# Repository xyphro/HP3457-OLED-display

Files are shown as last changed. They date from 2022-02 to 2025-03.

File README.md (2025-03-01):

# HP3457-OLED-display
A modern replacement for the low contrast HP3457 Multimeter LCD

HP3457 is a great multimeter of the pre Keysight and pre Agilent era from HP.
If you do some research on it, you get to learn a lot of details of how much nice engineering work has been put into the development of this multimeter. It is certainly one of the things, that was developed by great experienced engineers and is a masterpiece in finding proper solutions for technical challenges to push accuracy but also measurement speed on the right level.

HOWEVER: The display is crap. It is a low contrast display with small characters and extremly hard to read under most conditions. When I got mine, I rarely used it just for that reason.

I researched a bit on possible options and found 2 solutions:
- Mount a backlight behind the LCD. This is a very risky task, but I tried it out: The contrast gets even worse and actually it felt even like a downgrade of the display.
- A great sophisticated replacement LED display done by an EEVBlog user called "Xi": [https://www.eevblog.com/forum/projects/led-display-for-hp-3457a-multimeter-i-did-it-)](https://www.eevblog.com/forum/projects/led-display-for-hp-3457a-multimeter-i-did-it-)). Unfortunately this solution requires some difficult production techniques (milling LED displays to insert dots/comma leds, milling PCBs, ...).

I looked for solutions that were simpler to realize, such as matching TFT IPS panels, big OLED screens but failed to find a matching display.

After long thinking I had an idea... Let's use the cheapest OLED display that have very good availability: 0.87" i2c displays from Aliexpress. They are smaller than the required 10mm digit distance and just fit also mechanically into the display housing, without the need to cut pieces of the housing away.

To explain the idea - here 2 pictures:

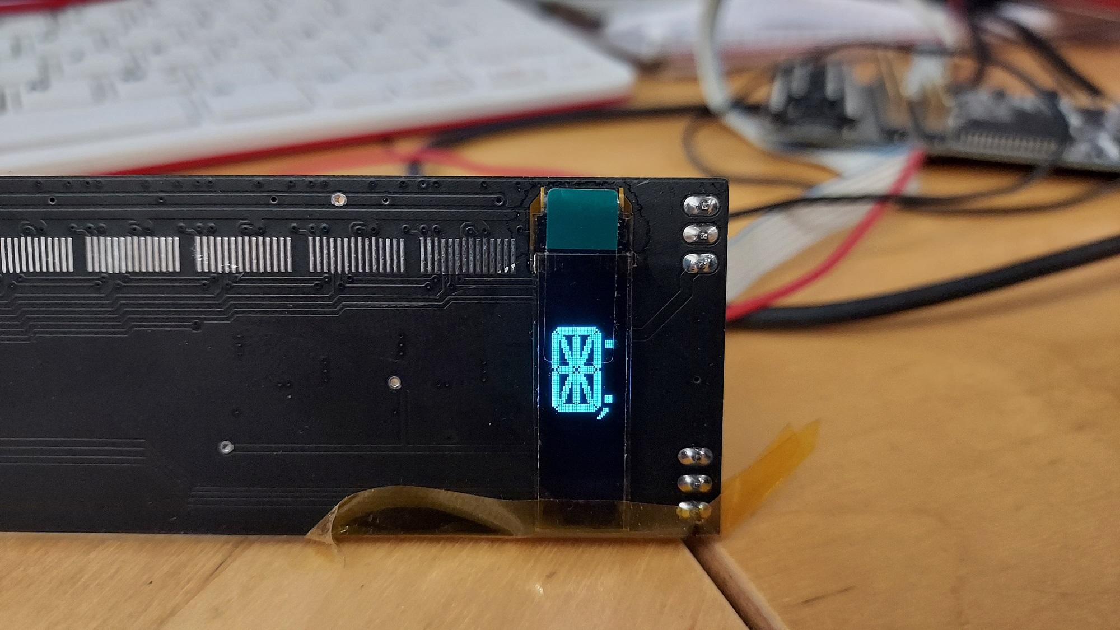
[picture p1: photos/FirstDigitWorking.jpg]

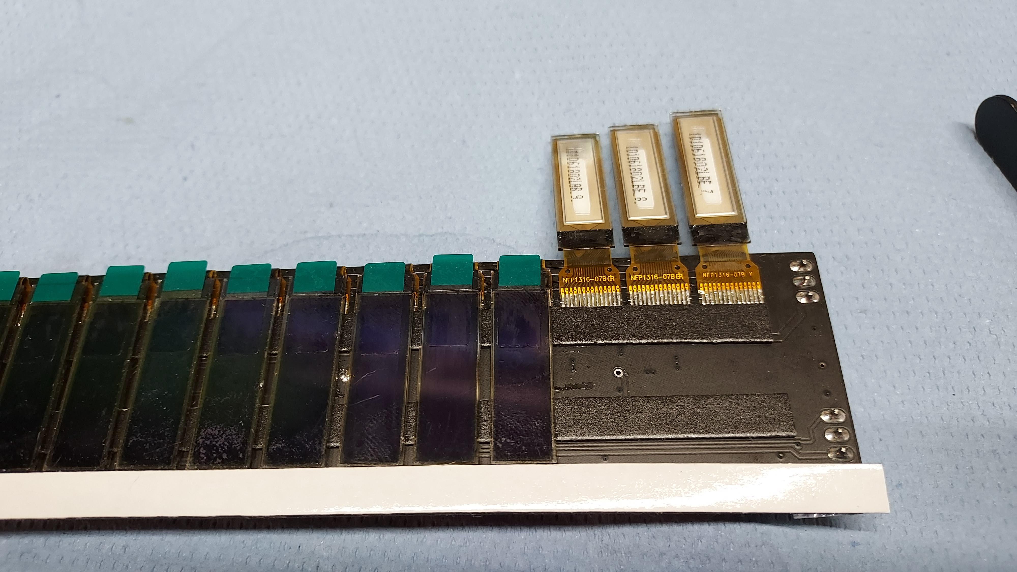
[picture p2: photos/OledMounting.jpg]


# The final result:

This video shows my final solution to the problem:

(https://youtu.be/EYaLf55-z-o) 

(Well, not the most entertaining video in this world, but... It serves the job :-) )

# Building the display yourself:

This repositories contains sourcecode and hw design files in "raw" formats, but also the binary output.

I ordered the PCBs originally at JLCPCB. Both PCBs are located on a single panel and you can cut them in half after receiving them. The Gerber files are located under hardware/gerber.
In case you want to modify the PCB yourself, feel free to do so (but share it back) and use the files located under hardware/eagle to create your own design.

The software was created using Atmel Studio 7.0 and the project can be directly opened with it for editing if desired.

Don't forget to program the fuses of the ATMega8 MCU and select 8 MHz internal RC oscillator as clock source (otherwise it runs too slow with its default 1 MHz clock only).

NOTE: Ensure to buy the 0.87" variant of the OLEDS. There are also popular 0.91" variants available, but they are to wide! 
I bought my displays directly on Aliexpress: https://de.aliexpress.com/item/1005001856921229.html
In case the above link stops working, search for items like "XABL 0.87 Inch OLED"

I personally tested SSD1336 based display. EEVBlog User Miti bought a display with a CH1115 controller. This controller has a different command set. We jointly have added support for CH1115 displays to the code. In case you have such a SSD1336 you will need to rebuild the software with the `#define DISPLAYTYPE_CH1115` being enabled within oled.c. Otherwise the original SSD1336 based OLED displays will be supported.

The prebuilt binaries provided in this repository are built for SSD1336 based displays.

# Annuciators:

Annuciators are the small triangles / TEXT labels underneath the display. They are used to signal state information of the multimeter.

There are 3 different flavors realized. To select them when building the software, edit this define in annuciatorsel.h:
#define ANNUCIATORS_PERSONALITY HP3457_ICONS

And select any of the 3 below ones:

- HP3457_ORIGINAL - These are the small triangles, that rely on the information printed on the frontpanel underneath the display:

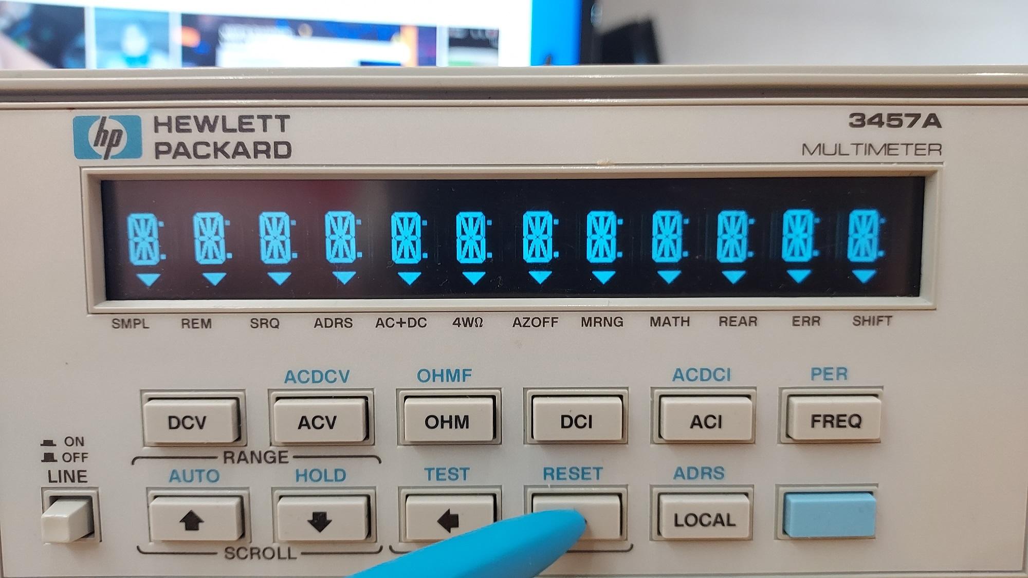
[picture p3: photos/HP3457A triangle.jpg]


- HP3457_ICONS  - Small textual labels on the OLEDS itself:

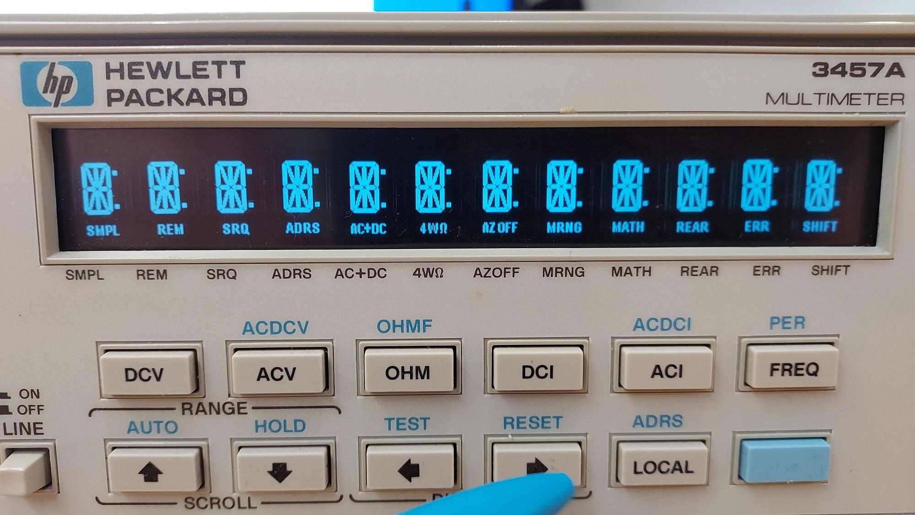
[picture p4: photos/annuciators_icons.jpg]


- HP3478_ICONS - textual labels matching the HP3478 / 3468 display

The software/hex folder also contains precompiled .hex images for those 3 different annuciators versions.

# Putting it together

After soldering the PCBs and flashing the MCU, you can mount the PCB to your lovely HP3457 multimeter. The original press fit DIP socket can be directly plugged into the PCB.
The OLED display requires a second voltage source to power the OLEDs themselfes. This can be an AC supply, but I recommend for the HP3457 to use the 5V voltage regulator in TO220 housing and connect the AC lines to pin 1 and 2, which is 12 V.

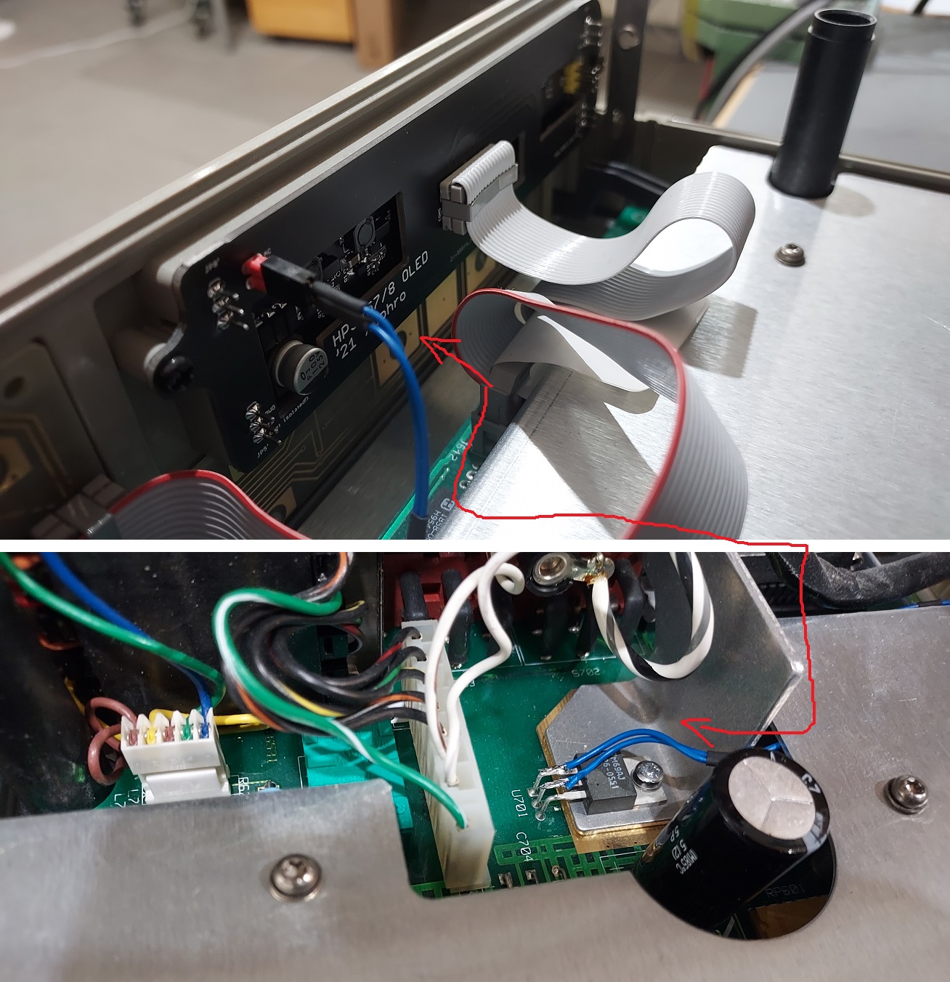
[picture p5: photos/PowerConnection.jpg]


The overall current consumption @12V supply is low and only about 30mA.

After mounting it looks like this from the internal side (the red supply header is unconnected here):

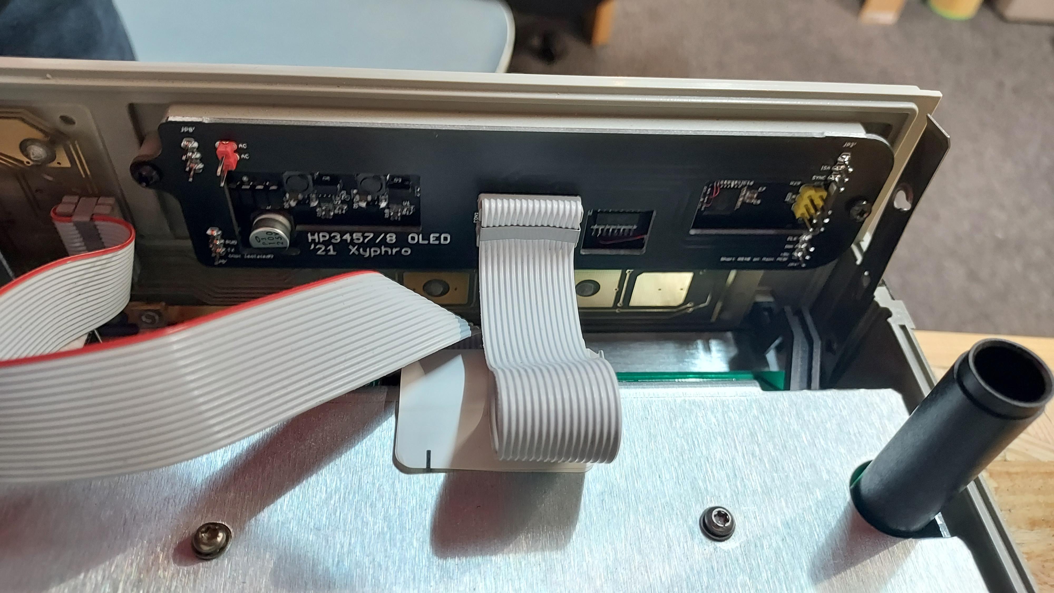
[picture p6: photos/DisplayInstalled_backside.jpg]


Enjoy your shiny new Display :-)

# Update 14th February 2025

## Experience after 3+ years

After 3 years of continuous use the Display still works very well. I have the feeling that the OLEDs got a tiny bit dimmer, but it is still tremendously better as the original LC-Display.

## Command coverage

Before this update (14th February 2025) only commands sent by HP3457a were supported. Though new commands were discovered, which triggered more searching for commands. 
I could find a few more and implemented it. See below table for an overview.

| Command code (12 bit HEX) | Command mnemonic | Implementation status / comment|
|---|---|---|
|028 |	WRA12L | Tested myself on HP3457a. |
|068 |	WRB12L | Tested myself on HP3457a. |
|0a8 |	WRC12L | Tested myself on HP3457a. |
|0e8 |	WRAB6L | Tested with playback of eevblog user Kawal's logic analyzer recording.|
|128 |	WRABC4L  | Not tested with HP instrument, have sent the command manually.|
|168 |	WRAB6R | Not tested with HP instrument, have sent the command manually.|
|1a8 |	WRABC4R  | Not tested with HP instrument, have sent the command manually.|
|1e8 |	WRA1L | Not tested with HP instrument, have sent the command manually.|
|228 |	WRB1L | Not tested with HP instrument, have sent the command manually.|
|268 |	WRC1L | Not tested with HP instrument, have sent the command manually.|
|2a8 |	WRA1R | Not tested with HP instrument, have sent the command manually.|
|2e8 |	WRB1R | Not tested with HP instrument, have sent the command manually.|
|328 |	WRC1R | Not tested with HP instrument, have sent the command manually.|
|368 |	WRAB1R | Not tested with HP instrument, have sent the command manually.|
|3a8 |	WRABC1L  | Not tested with HP instrument, have sent the command manually.|
|3e8 |	WRABC1R  | Not tested with HP instrument, have sent the command manually.|
|230 |  DISOFF | Implemented, but disabled. It results in wrong behavior on HP3457a. This command is supposed to turn the display OFF. It never gets sent on HP3457A.|
|320 |  DISTOG | Implemented, but disabled. It results in wrong behavior on HP3457a. This command is supposed to turn the display OFF. It gets sent on HP3457A, BUT turns the display continously on and off. Before this command always command code 0x2E0 is sent and it is unknown what this command does.|
|3FC |  DISCMP | Not implemented, because it is unknown what this command is supposed to do. It does not get sent by HP3457a.|
|3F0 | PERSCLT | Tested myself on HP3457a. Note that in previous FW versions it was not enabled.|
|2F0 | WRITAN  | Tested myself on HP3457a. Updates the annuciators.|
|2E0 | ??????  | Unknown command. It gets sent by HP3457a every time before the DISTOG command is sent.|

In case you have ANY information about the unknown HP LCD display commands let me know please. Or if you have a FW image of an original LCD display for analysis :-)

# Further links / Information

An eevblog thread on this project exists with lots of other users HW variant, experience and updates. E.g. HW variants can be found without isolator IC and using LDOs.

Have a look here: <a href="https://www.eevblog.com/forum/testgear/hp3548-hp3457-oled-display/" target="_blank">https://www.eevblog.com/forum/testgear/hp3548-hp3457-oled-display/</a>

In case you build the HW in this project note that it makes use of the 5V supply on the Display connector to supply the isolator IC. HP seems to put series resistors on the main PCB to limit the display IC current. You will very likely need to bridge these resistors - or build one of the eevblog variants with Isolator IC.

# Compatibility with other HP devices

The design might be compatible with other HP devices, but I personally only tested it with HP3547a. 
It is in the meantime confirmed, that the display works on HP3548 HP3478a and HP3852A too.

Chances are there that it might work for HP3468 and the HP66xx "tank" power supplies too. This is not tested by me (yet). If anybody is looking for adventures and tries this out, please feedback information to me, so that I can mark it is compatible here or share the required SW updates with a wider audience.

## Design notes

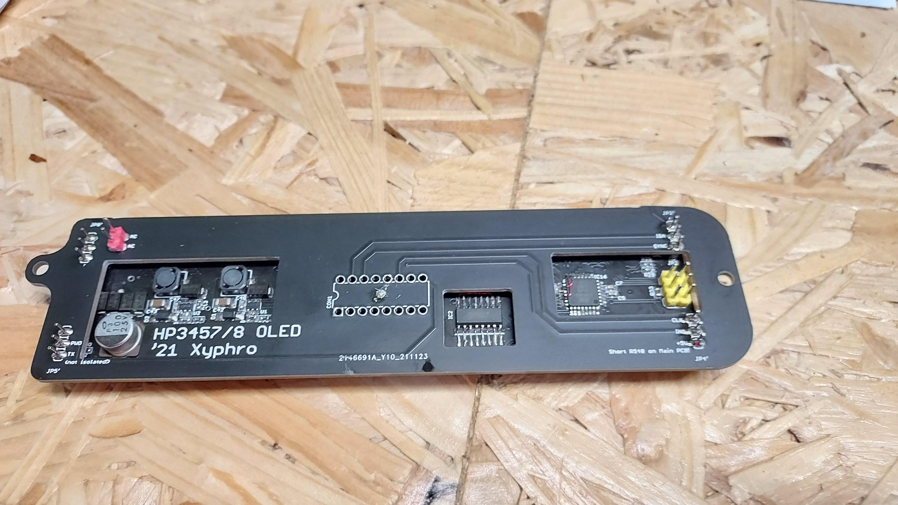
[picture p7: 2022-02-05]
photos/Display_Backside.jpg

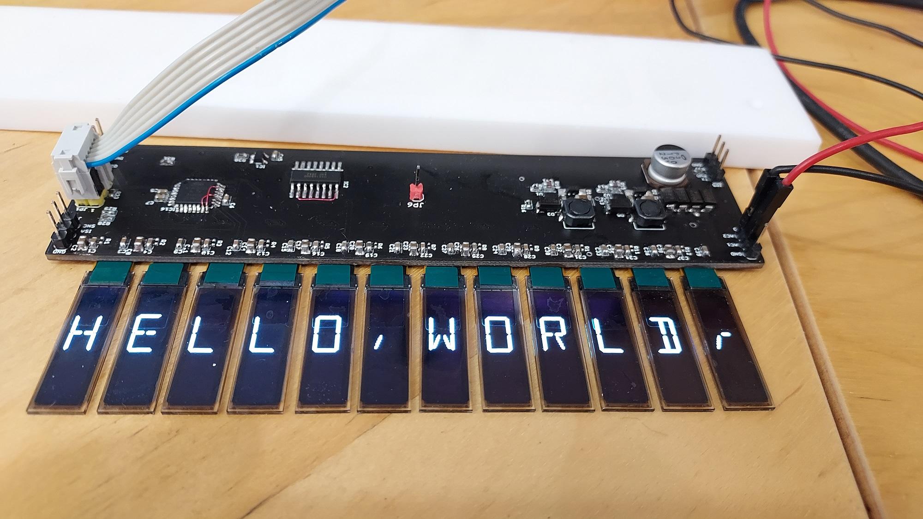
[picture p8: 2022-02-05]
photos/HelloWorld.jpg

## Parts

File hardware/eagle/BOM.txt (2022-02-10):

Qty Value        Device        Package          Parts                                                                                                              Description                                  MF MPN          OC_FARNELL OC_NEWARK TP_SIGNAL_NAME
1                DIL16BIGHOLE  DIL16BIGHOLE     CON1                                                                                                               Dual In Line / Socket                                                                           
2                PINHD-1X1     1X01             JP6, JP7                                                                                                           PIN HEADER                                                                                      
8                PINHD-1X3     1X03             JP2, JP2', JP3, JP3', JP4, JP4', JP5, JP5'                                                                         PIN HEADER                                                                                      
1                PINHD-2X3     2X03             JP1                                                                                                                PIN HEADER                                                                                      
2   100k         R0603         R0603            R13, R16                                                                                                                                                                                                           
4   100n         C0603         C0603            C5, C6, C7, C45                                                                                                                                                                                                    
1   100u/25V     CPOL-EUE      PANASONIC_E      C44                                                                                                                POLARIZED CAPACITOR, European symbol                                                            
2   10k          R0603         R0603            R14, R17                                                                                                                                                                                                           
2   10n          C0603         C0603            C40, C47                                                                                                                                                                                                           
2   1N4148       DIODE-DO214AC DO214AC          D1, D2                                                                                                             DIODE                                                                                           
2   1n           C0603         C0603            C41, C48                                                                                                                                                                                                           
6   2k           R0603         R0603            R28, R29, R30, R31, R32, R33                                                                                                                                                                                       
24  2u2          C0603         C0603            C1, C3, C4, C9, C10, C12, C13, C15, C16, C18, C19, C21, C22, C24, C25, C27, C28, C30, C31, C33, C34, C36, C37, C39                                                                                                 
1   31K6         R0603         R0603            R15                                                                                                                                                                                                                
12  4u7          C0805         C0805            C2, C8, C11, C14, C17, C20, C23, C26, C29, C32, C35, C38                                                                                                                                                           
12  560k         R0402         R0402            R1, R2, R3, R4, R5, R6, R7, R8, R9, R10, R11, R12                                                                                                                                                                  
1   74AHC1G86DBV 74AHC1G86DBV  SOT23-5          IC1                                                                                                                2-input EXCLUSIV-OR gate                                                                        
1   84K          R0603         R0603            R18                                                                                                                                                                                                                
2   10uF         C1206         C1206            C42, C43                                                                                                                                                                                                           
1   ISO7240      ISO7240       SO-16DW          IC2                                                                                                                HIGH SPEED QUAD DIGITAL ISOLATORS               ISO7240MDW   1755124    58M0385                 
2   PISA2408-100M-04  L-EUPIS24XX   PIS24XX          L1, L2                                                                                                                                                                                                             
2   LM2734YMK/NOPB  LM2734-TSOT6  TSOT6            U1, U2                                                                                                             Thin SOT23 1A Load Step-Down DC-DC Regulator                                                    
1   MEGA8-AI     MEGA8-AI      TQFP32-08        IC16                                                                                                               MICROCONTROLLER                                 ATMEGA8-16AU 9171371    73M8863                 
12  OLED0.87     OLED0.87      OLED0.87         IC17, IC18, IC19, IC20, IC21, IC22, IC23, IC24, IC25, IC26, IC27, IC28                                                                                                                                             
2   PTR1PAD1-13Y PTR1PAD1-13Y  P1-13Y           TP1, TP2                                                                                                           TEST PIN                                                                                        
6   SS 14L       SS14L    SOD-123_MINI-SMA D3, D4, D5, D6, D7, D8                                                                                             Molded plasitc,JEDEC SOD-123/Mini SMA

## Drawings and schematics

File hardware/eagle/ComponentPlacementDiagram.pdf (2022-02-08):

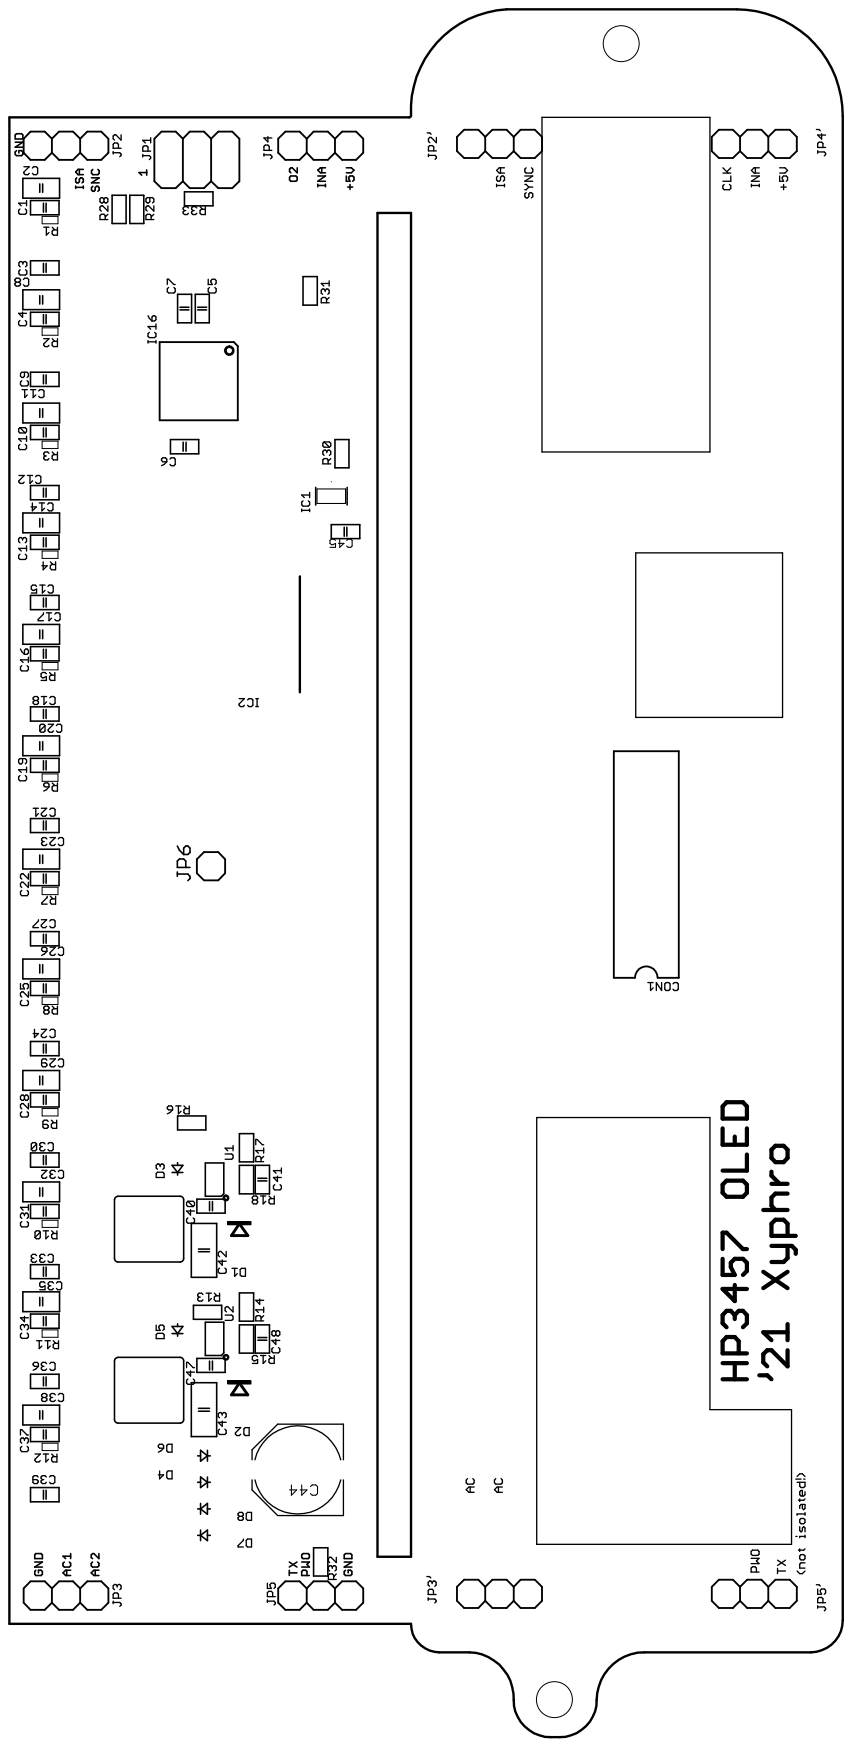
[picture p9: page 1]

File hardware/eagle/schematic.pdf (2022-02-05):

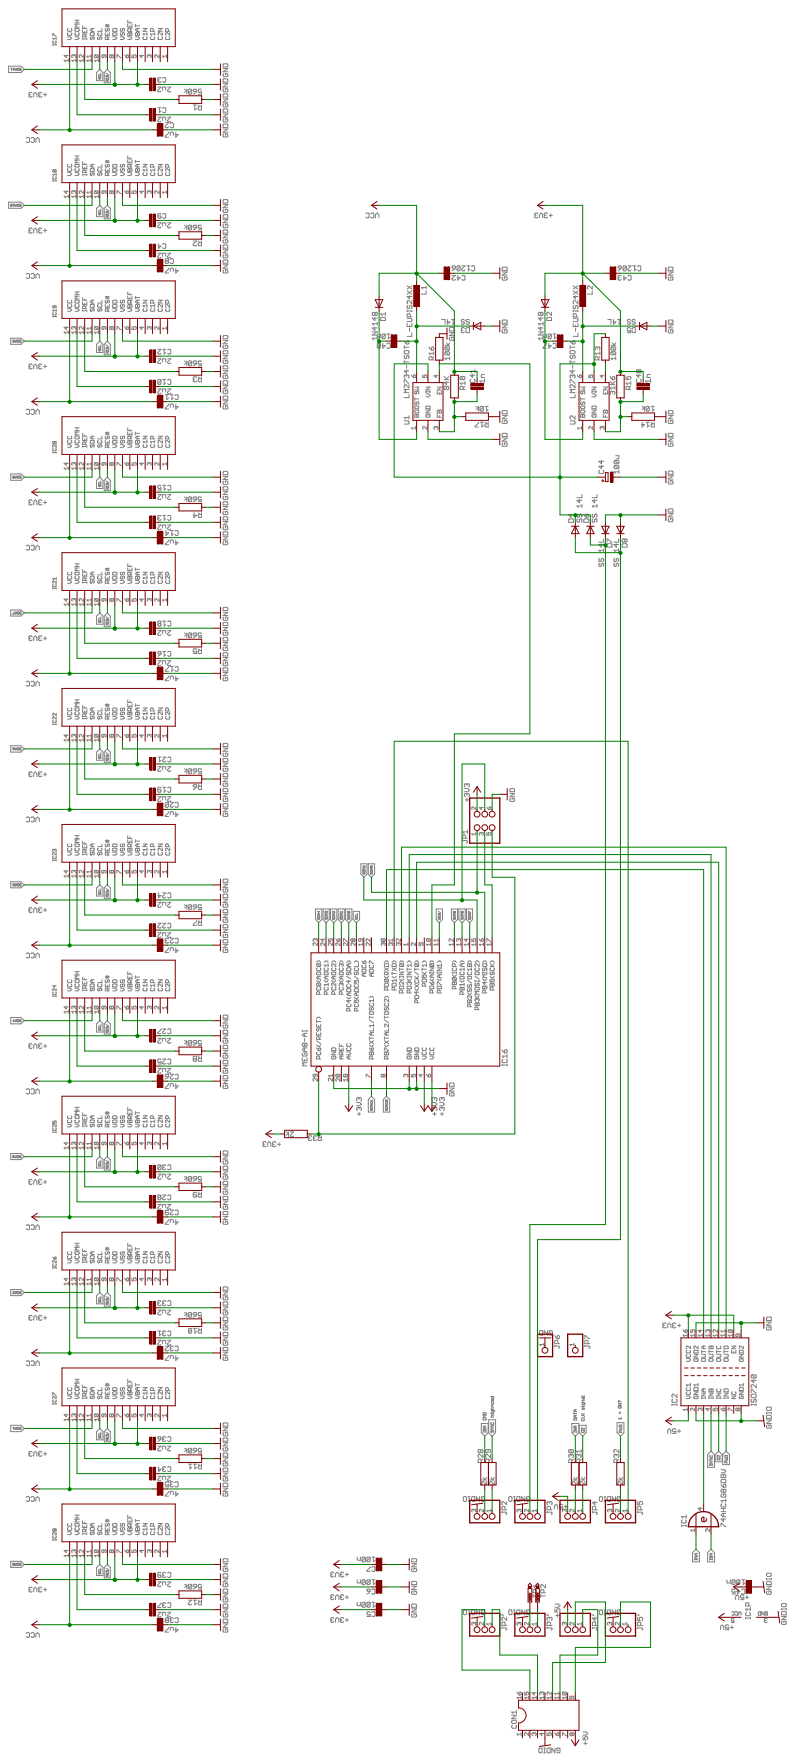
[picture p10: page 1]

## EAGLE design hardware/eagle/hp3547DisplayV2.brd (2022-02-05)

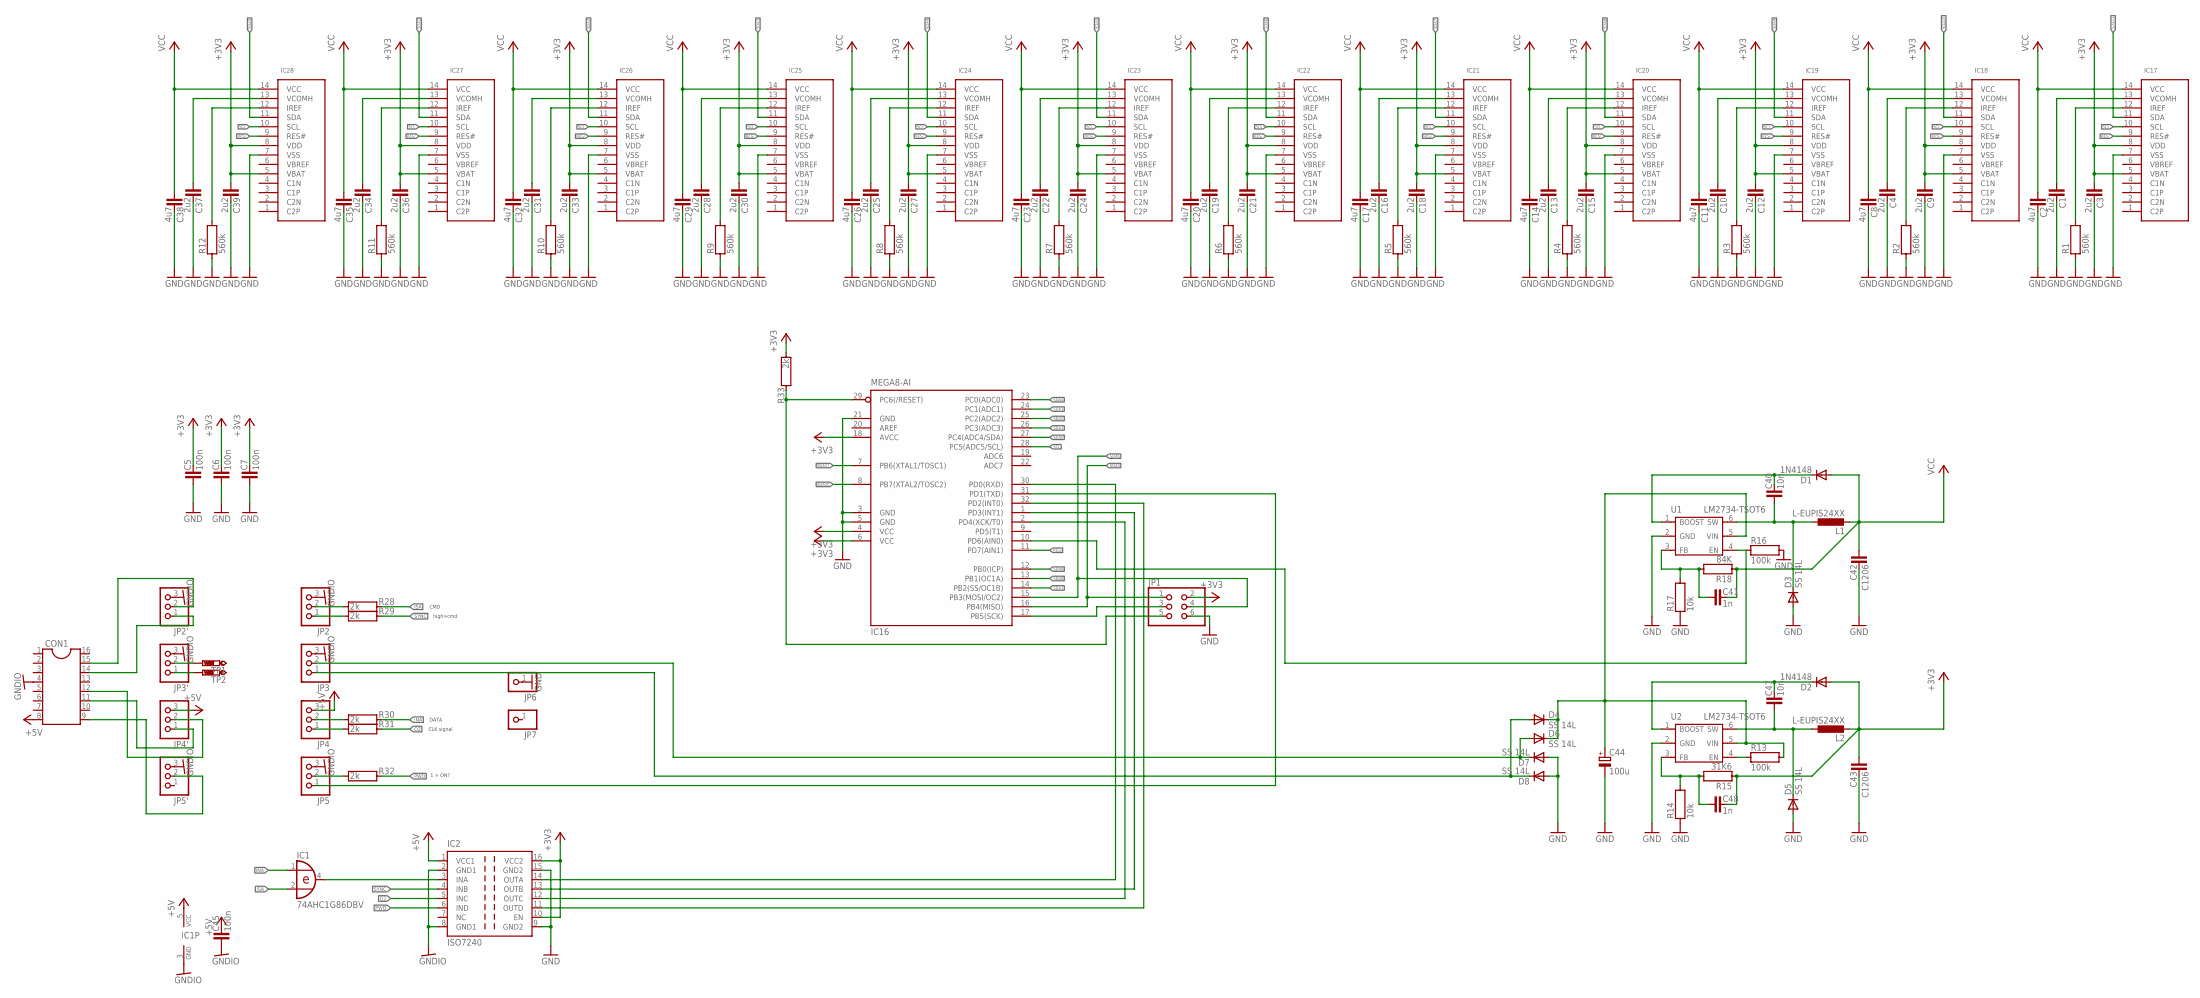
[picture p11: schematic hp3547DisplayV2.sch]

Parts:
C1, C3, C4, C9, C10, C12, C13, C15, C16, C18, C19, C21, C22, C24, C25, C27, C28, C30, C31, C33, C34, C36, C37, C39: 2u2; C0603
C2, C8, C11, C14, C17, C20, C23, C26, C29, C32, C35, C38: 4u7; C0805
C5, C6, C7, C45: 100n; C0603
C40, C47: 10n; C0603
C41, C48: 1n; C0603
C42, C43: C1206
C44: 100u; PANASONIC_E
CON1: DIL16BIGHOLE
D1, D2: 1N4148; DO214AC
D3, D4, D5, D6, D7, D8: SS 14L; SOD-123_MINI-SMA
IC1: 74AHC1G86DBV; SOT23-5
IC2: ISO7240; SO-16DW
IC16: MEGA8-AI; TQFP32-08
IC17, IC18, IC19, IC20, IC21, IC22, IC23, IC24, IC25, IC26, IC27, IC28: OLED0.87
JP1: PINHD-2X3; 2X03
JP2, JP2', JP3, JP3', JP4, JP4', JP5, JP5': PINHD-1X3; 1X03
JP6, JP7: PINHD-1X1; 1X01
L1, L2: L-EUPIS24XX; PIS24XX
R1, R2, R3, R4, R5, R6, R7, R8, R9, R10, R11, R12: 560k; R0402
R13, R16: 100k; R0603
R14, R17: 10k; R0603
R15: 31K6; R0603
R18: 84K; R0603
R28, R29, R30, R31, R32, R33: 2k; R0603
TP1, TP2: PTR1PAD1-13Y; P1-13Y
U1, U2: LM2734-TSOT6; TSOT6

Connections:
+3V3: C3.1, C5.2, C6.2, C7.2, C9.1, C12.1, C15.1, C18.1, C21.1, C24.1, C27.1, C30.1, C33.1, C36.1, C39.1, C43.1, C48.2, D2.A, IC2.10 (EN), IC2.16 (VCC2), IC16.4 (VCC), IC16.6 (VCC), IC16.18 (AVCC), IC17.5 (VBAT), IC17.8 (VDD), IC18.5 (VBAT), IC18.8 (VDD), IC19.5 (VBAT), IC19.8 (VDD), IC20.5 (VBAT), IC20.8 (VDD), IC21.5 (VBAT), IC21.8 (VDD), IC22.5 (VBAT), IC22.8 (VDD), IC23.5 (VBAT), IC23.8 (VDD), IC24.5 (VBAT), IC24.8 (VDD), IC25.5 (VBAT), IC25.8 (VDD), IC26.5 (VBAT), IC26.8 (VDD), IC27.5 (VBAT), IC27.8 (VDD), IC28.5 (VBAT), IC28.8 (VDD), JP1.2, L2.1 (2), R15.1, R33.2
+5V: C45.2, CON1.8, IC1.5 (VCC), IC2.1 (VCC1), JP4.3, JP4'.3
GND: C1.2, C2.2, C3.2, C4.2, C5.1, C6.1, C7.1, C8.2, C9.2, C10.2, C11.2, C12.2, C13.2, C14.2, C15.2, C16.2, C17.2, C18.2, C19.2, C20.2, C21.2, C22.2, C23.2, C24.2, C25.2, C26.2, C27.2, C28.2, C29.2, C30.2, C31.2, C32.2, C33.2, C34.2, C35.2, C36.2, C37.2, C38.2, C39.2, C42.2, C43.2, C44.-, D3.A, D5.A, D7.A, D8.A, IC2.9 (GND2), IC2.15 (GND2), IC16.3 (GND), IC16.5 (GND), IC16.21 (GND), IC17.7 (VSS), IC18.7 (VSS), IC19.7 (VSS), IC20.7 (VSS), IC21.7 (VSS), IC22.7 (VSS), IC23.7 (VSS), IC24.7 (VSS), IC25.7 (VSS), IC26.7 (VSS), IC27.7 (VSS), IC28.7 (VSS), JP1.6, JP6.1, R1.1, R2.1, R3.1, R4.1, R5.1, R6.1, R7.1, R8.1, R9.1, R10.1, R11.1, R12.1, R14.1, R16.2, R17.1, U1.2 (GND), U2.2 (GND)
GNDIO: C45.1, CON1.4, IC1.3 (GND), IC2.2 (GND1), IC2.8 (GND1), JP2.3, JP2'.3, JP3.3, JP3'.3, JP5.3, JP5'.3
INA: IC1.1 (I0), R30.1
ISA: IC1.2 (I1), R28.1
unnamed: IC18.12 (IREF), R2.2
unnamed: C4.1, IC18.13 (VCOMH)
unnamed: IC17.12 (IREF), R1.2
unnamed: C1.1, IC17.13 (VCOMH)
unnamed: JP2.2, R28.2
unnamed: IC19.12 (IREF), R3.2
unnamed: JP2.1, R29.2
unnamed: C10.1, IC19.13 (VCOMH)
unnamed: JP4.2, R30.2
unnamed: IC20.12 (IREF), R4.2
unnamed: C13.1, IC20.13 (VCOMH)
unnamed: JP4.1, R31.2
unnamed: IC21.12 (IREF), R5.2
unnamed: C16.1, IC21.13 (VCOMH)
unnamed: JP5.2, R32.2
unnamed: IC22.12 (IREF), R6.2
unnamed: C19.1, IC22.13 (VCOMH)
unnamed: C40.2, D1.C, U1.1 (BOOST)
unnamed: IC23.12 (IREF), R7.2
unnamed: C22.1, IC23.13 (VCOMH)
unnamed: C40.1, D3.C, L1.2 (1), U1.6 (SW)
unnamed: IC24.12 (IREF), R8.2
unnamed: C25.1, IC24.13 (VCOMH)
unnamed: C47.2, D2.C, U2.1 (BOOST)
unnamed: IC25.12 (IREF), R9.2
unnamed: C28.1, IC25.13 (VCOMH)
unnamed: C47.1, D5.C, L2.2 (1), U2.6 (SW)
unnamed: IC26.12 (IREF), R10.2
unnamed: C31.1, IC26.13 (VCOMH)
unnamed: C48.1, R14.2, R15.2, U2.3 (FB)
unnamed: IC27.12 (IREF), R11.2
unnamed: C34.1, IC27.13 (VCOMH)
unnamed: R13.1, U2.4 (EN)
unnamed: IC28.12 (IREF), R12.2
unnamed: C37.1, IC28.13 (VCOMH)
unnamed: IC16.31 (PD1(TXD)), JP5.1
unnamed: C41.1, R17.2, R18.2, U1.3 (FB)
unnamed: IC16.10 (PD6(AIN0)), R16.1, U1.4 (EN)
unnamed: JP3'.1, TP2.TP
unnamed: JP3'.2, TP1.TP
unnamed: D6.A, D7.C, JP3.2
unnamed: D4.A, D8.C, JP3.1
unnamed: IC2.14 (OUTA), IC16.30 (PD0(RXD))
unnamed: IC1.4 (O), IC2.3 (INA)
unnamed: IC2.12 (OUTC), IC16.2 (PD4(XCK/T0))
unnamed: IC2.13 (OUTB), IC16.1 (PD3(INT1))
unnamed: IC2.11 (OUTD), IC16.32 (PD2(INT0))
unnamed: IC16.29 (PC6(/RESET)), JP1.5, R33.1
unnamed: CON1.9, JP5'.2
unnamed: IC16.17 (PB5(SCK)), JP1.3
unnamed: CON1.11, JP4'.1
unnamed: CON1.12, JP4'.2
unnamed: CON1.14, JP2'.1
unnamed: CON1.15, JP2'.2
O2: IC2.5 (INC), R31.1
PWO: IC2.6 (IND), R32.1
RES/: IC16.11 (PD7(AIN1)), IC17.9 (RES#), IC18.9 (RES#), IC19.9 (RES#), IC20.9 (RES#), IC21.9 (RES#), IC22.9 (RES#), IC23.9 (RES#), IC24.9 (RES#), IC25.9 (RES#), IC26.9 (RES#), IC27.9 (RES#), IC28.9 (RES#)
SCL: IC16.28 (PC5(ADC5/SCL)), IC17.10 (SCL), IC18.10 (SCL), IC19.10 (SCL), IC20.10 (SCL), IC21.10 (SCL), IC22.10 (SCL), IC23.10 (SCL), IC24.10 (SCL), IC25.10 (SCL), IC26.10 (SCL), IC27.10 (SCL), IC28.10 (SCL)
SDA0: IC16.27 (PC4(ADC4/SDA)), IC28.11 (SDA)
SDA1: IC16.26 (PC3(ADC3)), IC27.11 (SDA)
SDA2: IC16.25 (PC2(ADC2)), IC26.11 (SDA)
SDA3: IC16.24 (PC1(ADC1)), IC25.11 (SDA)
SDA4: IC16.23 (PC0(ADC0)), IC24.11 (SDA)
SDA5: IC16.16 (PB4(MISO)), IC23.11 (SDA), JP1.1
SDA6: IC16.15 (PB3(MOSI/OC2)), IC22.11 (SDA), JP1.4
SDA7: IC16.14 (PB2(SS/OC1B)), IC21.11 (SDA)
SDA8: IC16.13 (PB1(OC1A)), IC20.11 (SDA)
SDA9: IC16.12 (PB0(ICP)), IC19.11 (SDA)
SDA10: IC16.8 (PB7(XTAL2/TOSC2)), IC18.11 (SDA)
SDA11: IC16.7 (PB6(XTAL1/TOSC1)), IC17.11 (SDA)
SYNC: IC2.4 (INB), R29.1
VCC: C2.1, C8.1, C11.1, C14.1, C17.1, C20.1, C23.1, C26.1, C29.1, C32.1, C35.1, C38.1, C41.2, C42.1, D1.A, IC17.14 (VCC), IC18.14 (VCC), IC19.14 (VCC), IC20.14 (VCC), IC21.14 (VCC), IC22.14 (VCC), IC23.14 (VCC), IC24.14 (VCC), IC25.14 (VCC), IC26.14 (VCC), IC27.14 (VCC), IC28.14 (VCC), L1.1 (2), R18.1
VIN: C44.+, D4.C, D6.C, R13.2, U1.5 (VIN), U2.5 (VIN)

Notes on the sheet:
CLK signal
DATA
CMD
high=cmd
1 = ON?

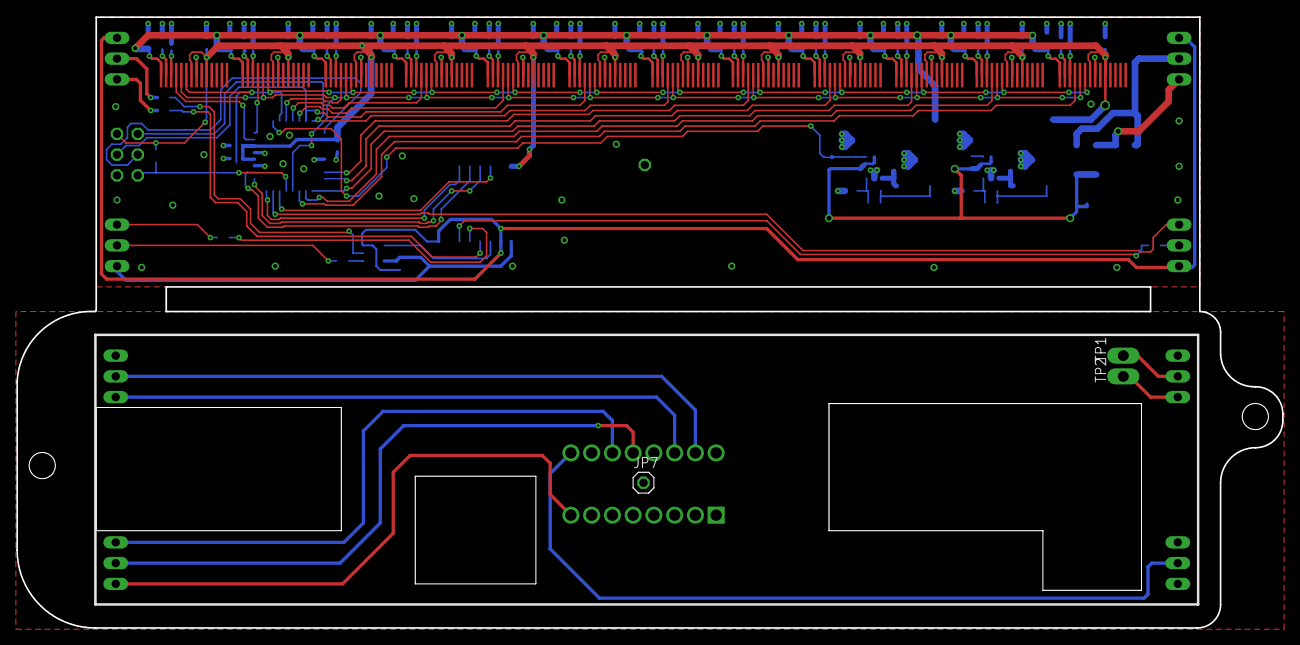
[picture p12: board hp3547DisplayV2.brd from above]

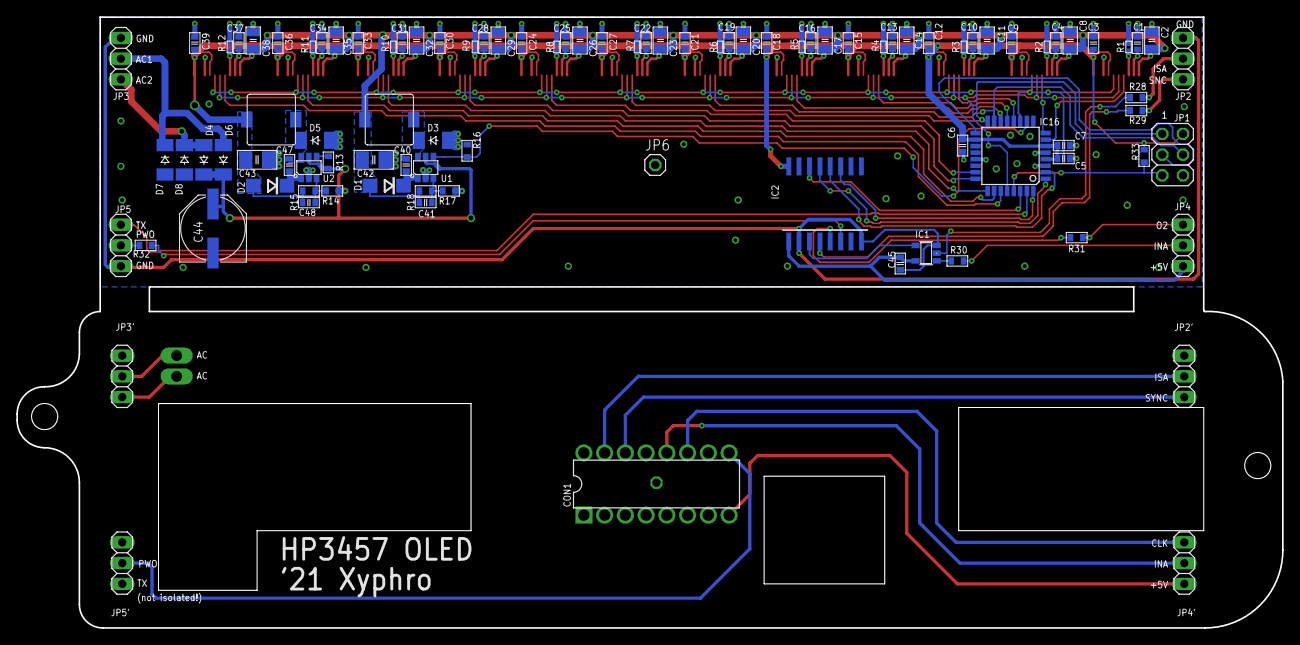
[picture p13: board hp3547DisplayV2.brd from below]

Board: 2 copper layers, 154.9 x 74.8 mm, 112 parts (97 on the bottom side), 79 nets.

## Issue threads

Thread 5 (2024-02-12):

Jumpers on atmega wire

subzero2379, 2024-02-12:
I see some jumper wire on atmega
Need to do the same jumpers.
Im building the oled for 3478a. Dmm

xyphro, 2024-02-12:
The wire patches are not required. Only for the first prototype i needed them but have fixed the design

Closed 2024-02-16.

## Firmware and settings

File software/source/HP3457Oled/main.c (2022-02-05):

/*
 * HP3457Oled.c
 *
 * Created: 30.01.2022 18:13:05
 * Author : xyphro
 */ 

#include <avr/io.h>
#include "oled.h"
#include "pari2c.h"

#include <util/delay.h>
#include "hp_charset.h"
#include "hpdispprot.h"




int main(void)
{	
	oled_init();
	hpdp_init();
	
	DDRD &= ~(1<<3);
	DDRD |= (1<<5);
	
	uint16_t i=0;
    while (1) 
    {
		uint8_t update = hpdp_update();
		if ( update & HPDP_UPDATE_DIGITS )
		{
			oled_repaint_digits(53);
		}
		if ( update & HPDP_UPDATE_ANNUCIATORS )
		{
			oled_repaint_annuciators(53-16);
		}
    }
}

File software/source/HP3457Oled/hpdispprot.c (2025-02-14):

#include <util/delay.h>
#include <avr/io.h>
#include <avr/interrupt.h>
#include <avr/pgmspace.h>
#include "hp_charset.h"
#include "hpdispprot.h"

#include "oled.h"



/***********************************************************************
 * Connection scheme:
 * PD0(RXD)    = INA ^ ISA (data) (Actually it would not be required to do a HW XOR, but here it helped to save 
 *                                 money for a 8 line isolator IC. In case you don't want galvanic isolation, you 
 *                                 could optimize the XOR IC away).
 * PD3(INT1)   = SYNC (high = command, low = data)
 * PD4(XCK/T0) = O2 (clock)
 * PD2(INT0)   = PWO (power up)
 **
 * Principle: 
 * The HP3457 sends datagrams that are command + data payload based.
 * The SYNC line identifies if the data is a command (SYNC = HIGH) or data (SYNC = LOW).
 * A command has a bitlength of 10 bits, the data payload is variable in length as function of the received command
 * 
 * PD3 is programmed to generate an interrupt on a rising edge (=start of a command).
 *   Once the interrupt arrives, To will be setup to generate an interrupt for every rising edge of the O2=clock line.
 * This timer interrupt does receive bits and store them for later processing.
 *
 * The actual display content will be flagged as valid so that it can be updated if no command is received within 10 ms
 *
 * Credits to Xi from EEvblog for decoding!
 ***********************************************************************/

// Timeout value based on 7k8125 Hz clock (78 cycles ~= 10ms)
// If no commands are received within this period, the display will be updated
#define TIMEOUT_VALUE (78)


// Below commands are known commands and most of them interpreted. Unknown commands are not handled and get simply ignored
#define	CMD_WRA12L  (0x0a) /* = 0x0A x4 = 0x028 = write registers A for the 12 digits */
#define	CMD_WRB12L  (0x1a) /* = 0x1A x4 = 0x068 = write registers B for the 12 digits */
#define CMD_WRC12L  (0x2a) /* = 0x2A x4 = 0x0A8 = write registers C for the 12 digits */
#define	CMD_WRAB6L  (0x3a) /* = 0x3A x4 = 0x0E8 = shift left 6 digits and write registers AB for the 6 digits */
#define	CMD_WRABC4L (0x4a) /* = 0x4A x4 = 0x128 = shift left 4 digits and write registers ABC for the 4 digits */
#define	CMD_WRAB6R  (0x5a) /* = 0x5A x4 = 0x168 = shift right 6 digits and write registers AB for the 6 digits */
#define	CMD_WRABC4R (0x6a) /* = 0x6A x4 = 0x1a8 = shift right 4 digits and write registers ABC for the 4 digits */
#define	CMD_WRA1L   (0x7a) /* = 0x7A x4 = 0x1e8 = shift left 1 digit and write registers A for 1 digit */
#define	CMD_WRB1L   (0x8a) /* = 0x8A x4 = 0x228 = shift left 1 digit and write registers B for 1 digit */
#define	CMD_WRC1L   (0x9a) /* = 0x9A x4 = 0x268 = shift left 1 digit and write registers C for 1 digit */
#define	CMD_WRA1R   (0xaa) /* = 0xAA x4 = 0x2a8 = shift right 1 digit and write registers A for 1 digit */
#define	CMD_WRB1R   (0xba) /* = 0xBA x4 = 0x2e8 = shift right 1 digit and write registers B for 1 digit */
#define	CMD_WRAB1L  (0xca) /* = 0xCA x4 = 0x328 = shift left 1 digit and write registers AB for 1 digit */
#define	CMD_WRAB1R  (0xda) /* = 0xDA x4 = 0x368 = shift right 1 digit and write registers AB for 1 digit */
#define	CMD_WRABC1L (0xea) /* = 0xEA x4 = 0x3a8 = shift left 1 digit and write registers ABC for 1 digit */
#define	CMD_WRABC1R (0xfa) /* = 0xFA x4 = 0x3e8 = shift left 1 digit and write registers ABC for 1 digit */
#define	CMD_WRITAN  (0xbc) /* = 0xBC x4 = 0x2F0 = write the annunciators (eg the little arrows that are below the digits). The annunciators will follow in the data frame ("INA" line): there is one bit per annunciator, and the top right annunciator is transmitted first */

#define	CMD_DISOFF       (0x8C) /* = 0x8C x4 = 0x230 = Turn display off */
#define	CMD_DISTOG       (0xC8) /* = 0xC8 x4 = 0x320 = toggle the display ON/OFF (I don't know why this command is sent everytime (the sequence is always FC, B8, C8, BC, ...), maybe the unknow command B8 tells to switch the display OFF, then the C8 command swithes the display ON?) */
#define	CMD_PERSCLT      (0xfc) /* = 0xFC x4 = 0x3F0 = select the display if the following data field contains 0xF 0xD (that's always the case for HP3457a) */

volatile uint8_t hpdp_dat = 0;
volatile uint8_t hpdp_expectedsz = 0;
volatile uint8_t hpdp_sz = 0;
volatile bool    hpdp_nextiscmd;
volatile bool	hpdp_cmdisknown;
volatile uint8_t hpdp_msg[12], hpdp_cmd;
volatile uint8_t hpdp_updateflag; // update with information which part of the display should be update

volatile uint8_t hdpd_reg_a[12];  // 4 bit registers from that display content will be assembled
volatile uint8_t hdpd_reg_b[12];  // the character code is (reg_c&1<<6) | (reg_b&3)<<4 | reg_a
volatile uint8_t hdpd_reg_c[12];  // the period is encoded in reg_b bit 2 and 3

volatile bool    hpdp_displayselected = true; // used to handle the PERSCLT command - the default value can be incorrect - could not confirm it yet
volatile bool    hpdp_displayon       = true;  // Stores the on/off state of the display - the default value on has to be right, because HP3852a does never send a command to turn the display on

uint8_t cnt=0; // bitcounter for display command receiver

// PD3 interrupt - triggered on every rising edge of the PD3 pin 
ISR(INT1_vect)
{
	if (PIND & (1<<2))
	{ // only decode when PWO signal is high
		TCNT0 = -3; // Skip first 2 bits after SYNC edge
		TCCR0 = (7<<1); // enable Timer 0 (precondition here is, that TCNT is -3)
		hpdp_nextiscmd = true;
		cnt = 0;
	}
}


uint8_t kommaxlate  [] = {0, 2, 6, 3}; // none, period, colon, comma
uint8_t datalenxlate[] = {12, 12, 12, 12, 12, 12, 12, 1, 1, 1, 1, 1, 2, 2, 3, 3}; // payload count of all write command

// below function will trigger a display update 10ms after it was called
static void hpdp_scheduledisplayupdate(void)
{
	hpdp_updateflag |= HPDP_UPDATE_DIGITS;
	hpdp_updateflag |= HPDP_UPDATE_ANNUCIATORS;
	
	// Timer 1 is set as generic up counting counter and used as timeout to flag,
	// that the display should be updated.
	TCNT1H = (0xffff-TIMEOUT_VALUE) >> 8; TCNT1L = (0xffff-TIMEOUT_VALUE) & 0xff; // reset timer
	TCCR1B = (5<<0); // 8 MHz / 1024 = 7k8125 Hz => 16 bit timer value wraps every 8.4s, 8 bit LSB wraps every 32m768s
}
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

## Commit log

2022-02-05 Initial commit of all files
    [hp3547DisplayV2.GBL, hp3547DisplayV2.GBO, hp3547DisplayV2.GBP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]
2022-02-05 insert the correct photos
2022-02-05 "unmirror" the PDF schematic (Thanks Hexley!)
2022-02-06 Show PowerConnection
2022-02-08 Add BOM and component placement diagram
2025-02-15 Updated display reset timing
    The reset was so long, that commands from the supply were already sent and missed in the updates. Resulting e.g. in short phases of @@@@@@@@ being shown.
    [oled.c]
